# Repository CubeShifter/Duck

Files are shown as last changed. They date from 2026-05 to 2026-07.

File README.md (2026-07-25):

# Duck
An rp2040 devboard that can be coded up to play a loud noise when pressed with a keyboard switch. The original goal for the project was to make it play a loud noise of your choice when you press the switch, but i wanted to make it more customizable so now its a pcb that you can do whatever with. sadly i did privitize my lapse links cause i put some pii in them so you will just have to trust my :hs:

Screenies!

Schematic
Screenshot 2026-07-24 at 8 37 37 PM

I foget what its called(Dont mind the drc errors i forgot to rerun it)
Screenshot 2026-07-24 at 8 38 18 PM

3d Model of top:
  Screenshot 2026-07-24 at 8 39 08 PM

3d model of bottom:

Screenshot 2026-07-24 at 8 39 43 PM

# Steps for recreation:
Get the pcb fabricated, and solder on the componenets. I would highly reccomend PCBA, but you could also hand solder it. Once you build it, you can flash code on it like an rp2040 devboard. I want to see how people use the key and audio, so you should try using it somehow!

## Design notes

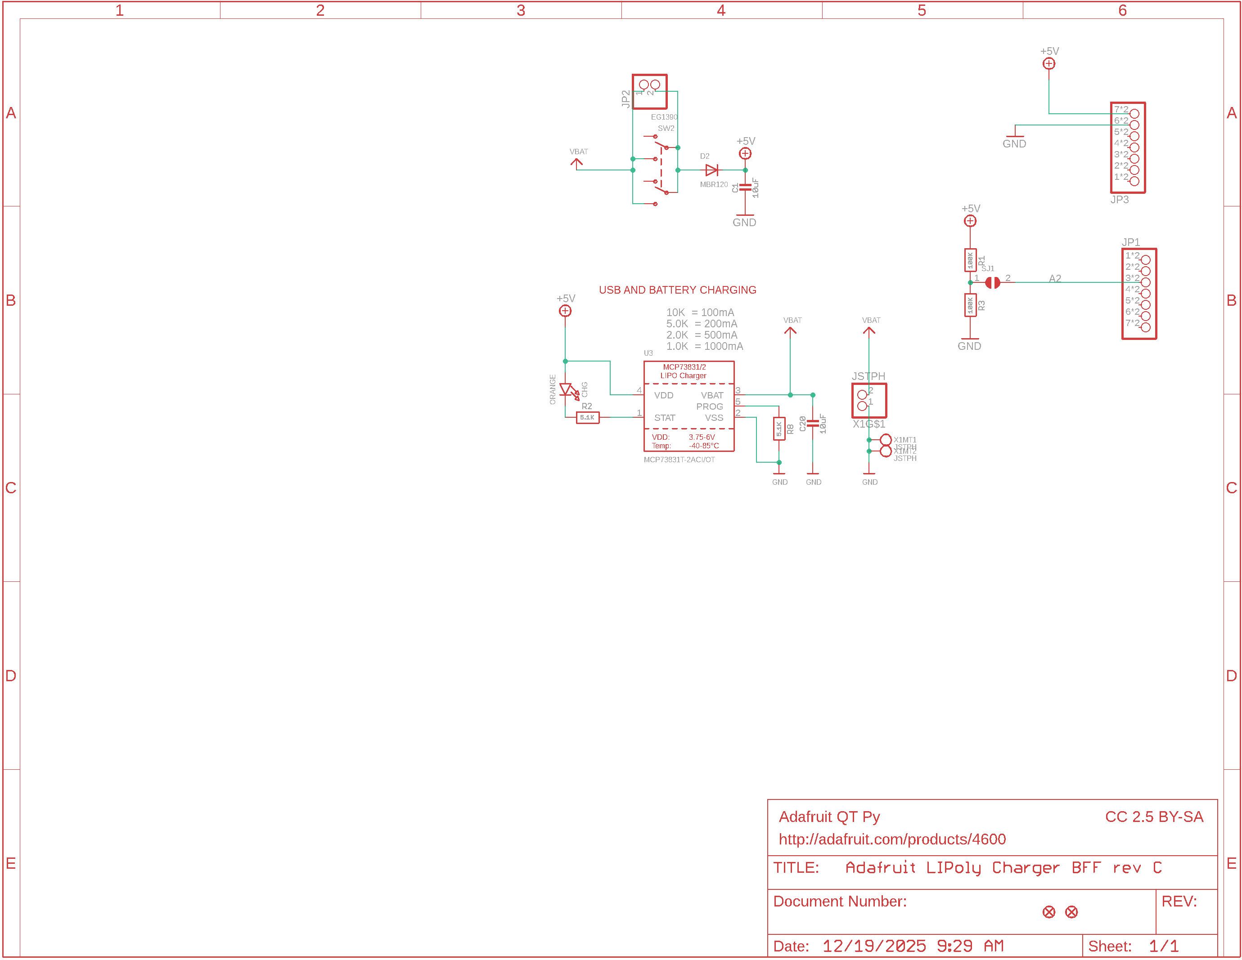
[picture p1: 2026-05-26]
Adafruit_Lipo_Bff_Sch.png

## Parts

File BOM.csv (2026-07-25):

Name | Usecase | Quantity | Unit Price(USD) | Link
RP2040 | Micrcontroller | 1 | 0.99 | https://www.lcsc.com/product-detail/C2040.html?s_z=n_q_t_rp2040
YXC Crystal Oscillators X322512MSB4SI | Oscillator | 1 | 0.48 | https://www.lcsc.com/product-detail/C9002.html?s_z=n_q_C9002&globalKeyword=C9002
Korean Hroparts Elec TYPE-C-31-M-12 | USBC thingy | 1 | 0.85 | https://www.lcsc.com/product-detail/C165948.html?s_z=n_q_C165948&globalKeyword=C165948
W25Q128JVS | Flash Chip | 1 | 2.5 | https://www.lcsc.com/product-detail/C97521.html?s_z=n_q_W25Q128JVS
XUNPU TS-1088-AR02016 | Reset Button | 1 | 0.05 | https://www.lcsc.com/product-detail/C720477.html?s_z=n_q_C720477&globalKeyword=C720477
NCP1117-3.3_SOT223 | 3.3v regulator | 1 | 0.032 | https://www.lcsc.com/product-detail/C20546.html?s_z=n_q_p_NCP1117-3.3_SOT223
MAX98357A | Audio Amp | 1 | 1.34 | https://www.lcsc.com/product-detail/C910544.html?s_z=n_q_MAX98357A
Mini Oval Speaker | Speaker! | 1 | 1.95 | https://www.adafruit.com/product/4227
3.7v battery | Battery!!!!! | 1 | 5.95 | https://www.adafruit.com/product/4237
SK6812Mini-E | Keeb Led | 1 | 0.44 | https://www.lcsc.com/product-detail/C5149201.html
HMX Bruise | Keyboard switch | 1 | 0.42 | https://milktooth.com/products/bruise
YAGEO CC0402KRX7R7BB104 | 0.1uF Ceramic Capacitor | 14 | 0.0086 | https://www.lcsc.com/product-detail/C60474.html?s_z=n_q_t_0.1uf%2520402
Samsung Electro-Mechanics CL05A105KO5NNNC | 1uf capacitor | 2 | 0.0091 | https://www.lcsc.com/product-detail/C29266.html?s_z=n_q_t_1uf%2520402
Samsung Electro-Mechanics CL10A106MA8NRNC | 10uf cap | 5 | 0.1258 | https://www.lcsc.com/product-detail/C96446.html?s_z=n_q_t_10uf%2520603
YAGEO RC0402FR-0727RL | 27 ohm resistor | 2 | 0.0048 | https://www.lcsc.com/product-detail/C138021.html?s_z=n_q_t_27ohm%2520402
YAGEO RC0402FR-071KL | 1k ohm resistor | 2 | 0.006 | https://www.lcsc.com/product-detail/C106235.html?s_z=n_q_t_1kohm%2520402
YAGEO RC0402FR-0710KL | 10k ohm resistor | 1 | 0.006 | https://www.lcsc.com/product-detail/C60490.html?s_z=n_q_t_10kohm%2520402
YAGEO RC0402FR-07100KL | 100k ohm resistor | 1 | 0.006 | https://www.lcsc.com/product-detail/C60491.html?s_z=n_q_t_100kohm%2520402
YAGEO RC0402FR-071ML | 1m ohm resistor | 1 | 0.006 | https://www.lcsc.com/product-detail/C138033.html?s_z=n_q_t_1000kohm%2520402
YAGEO RC0402FR-07330RL | 330 ohm resistor | 1 | 0.006 | https://www.lcsc.com/product-detail/C105875.html?s_z=n_q_t_330ohm%2520402
YAGEO RC0402FR-072KL | 2k ohm resistor | 2 | 0.006 | https://www.lcsc.com/product-detail/C60488.html?s_z=n_q_t_2kohm%2520402
YAGEO RC0402FR-075K1L | 5.1k ohm resistor | 2 | 0.006 | https://www.lcsc.com/product-detail/C105872.html?s_z=n_q_t_5.1kohm%2520402

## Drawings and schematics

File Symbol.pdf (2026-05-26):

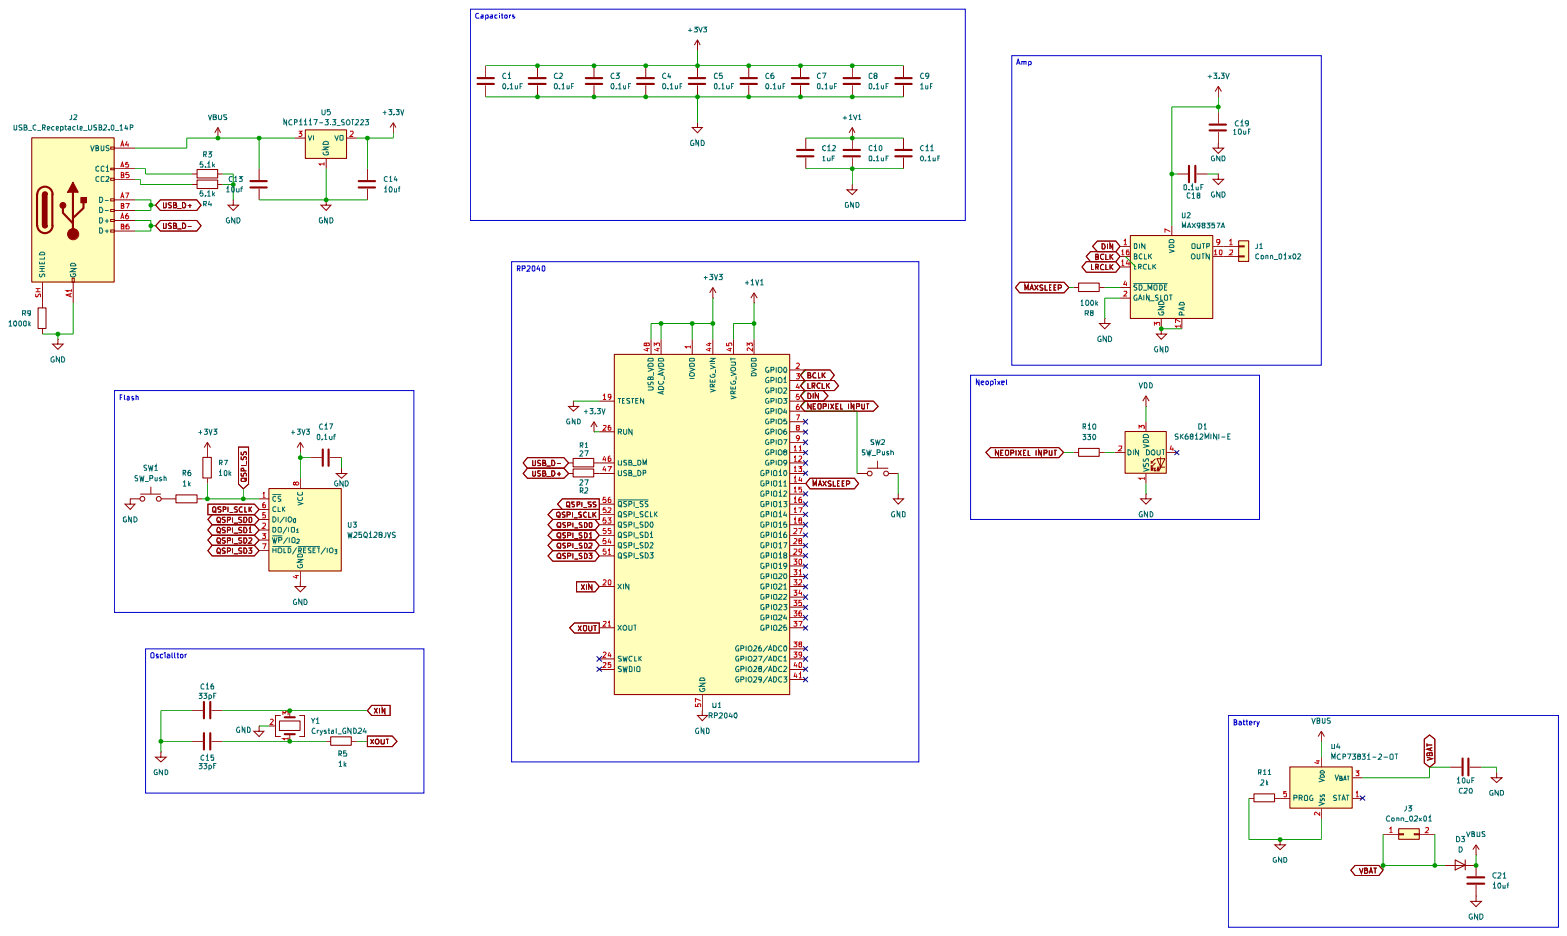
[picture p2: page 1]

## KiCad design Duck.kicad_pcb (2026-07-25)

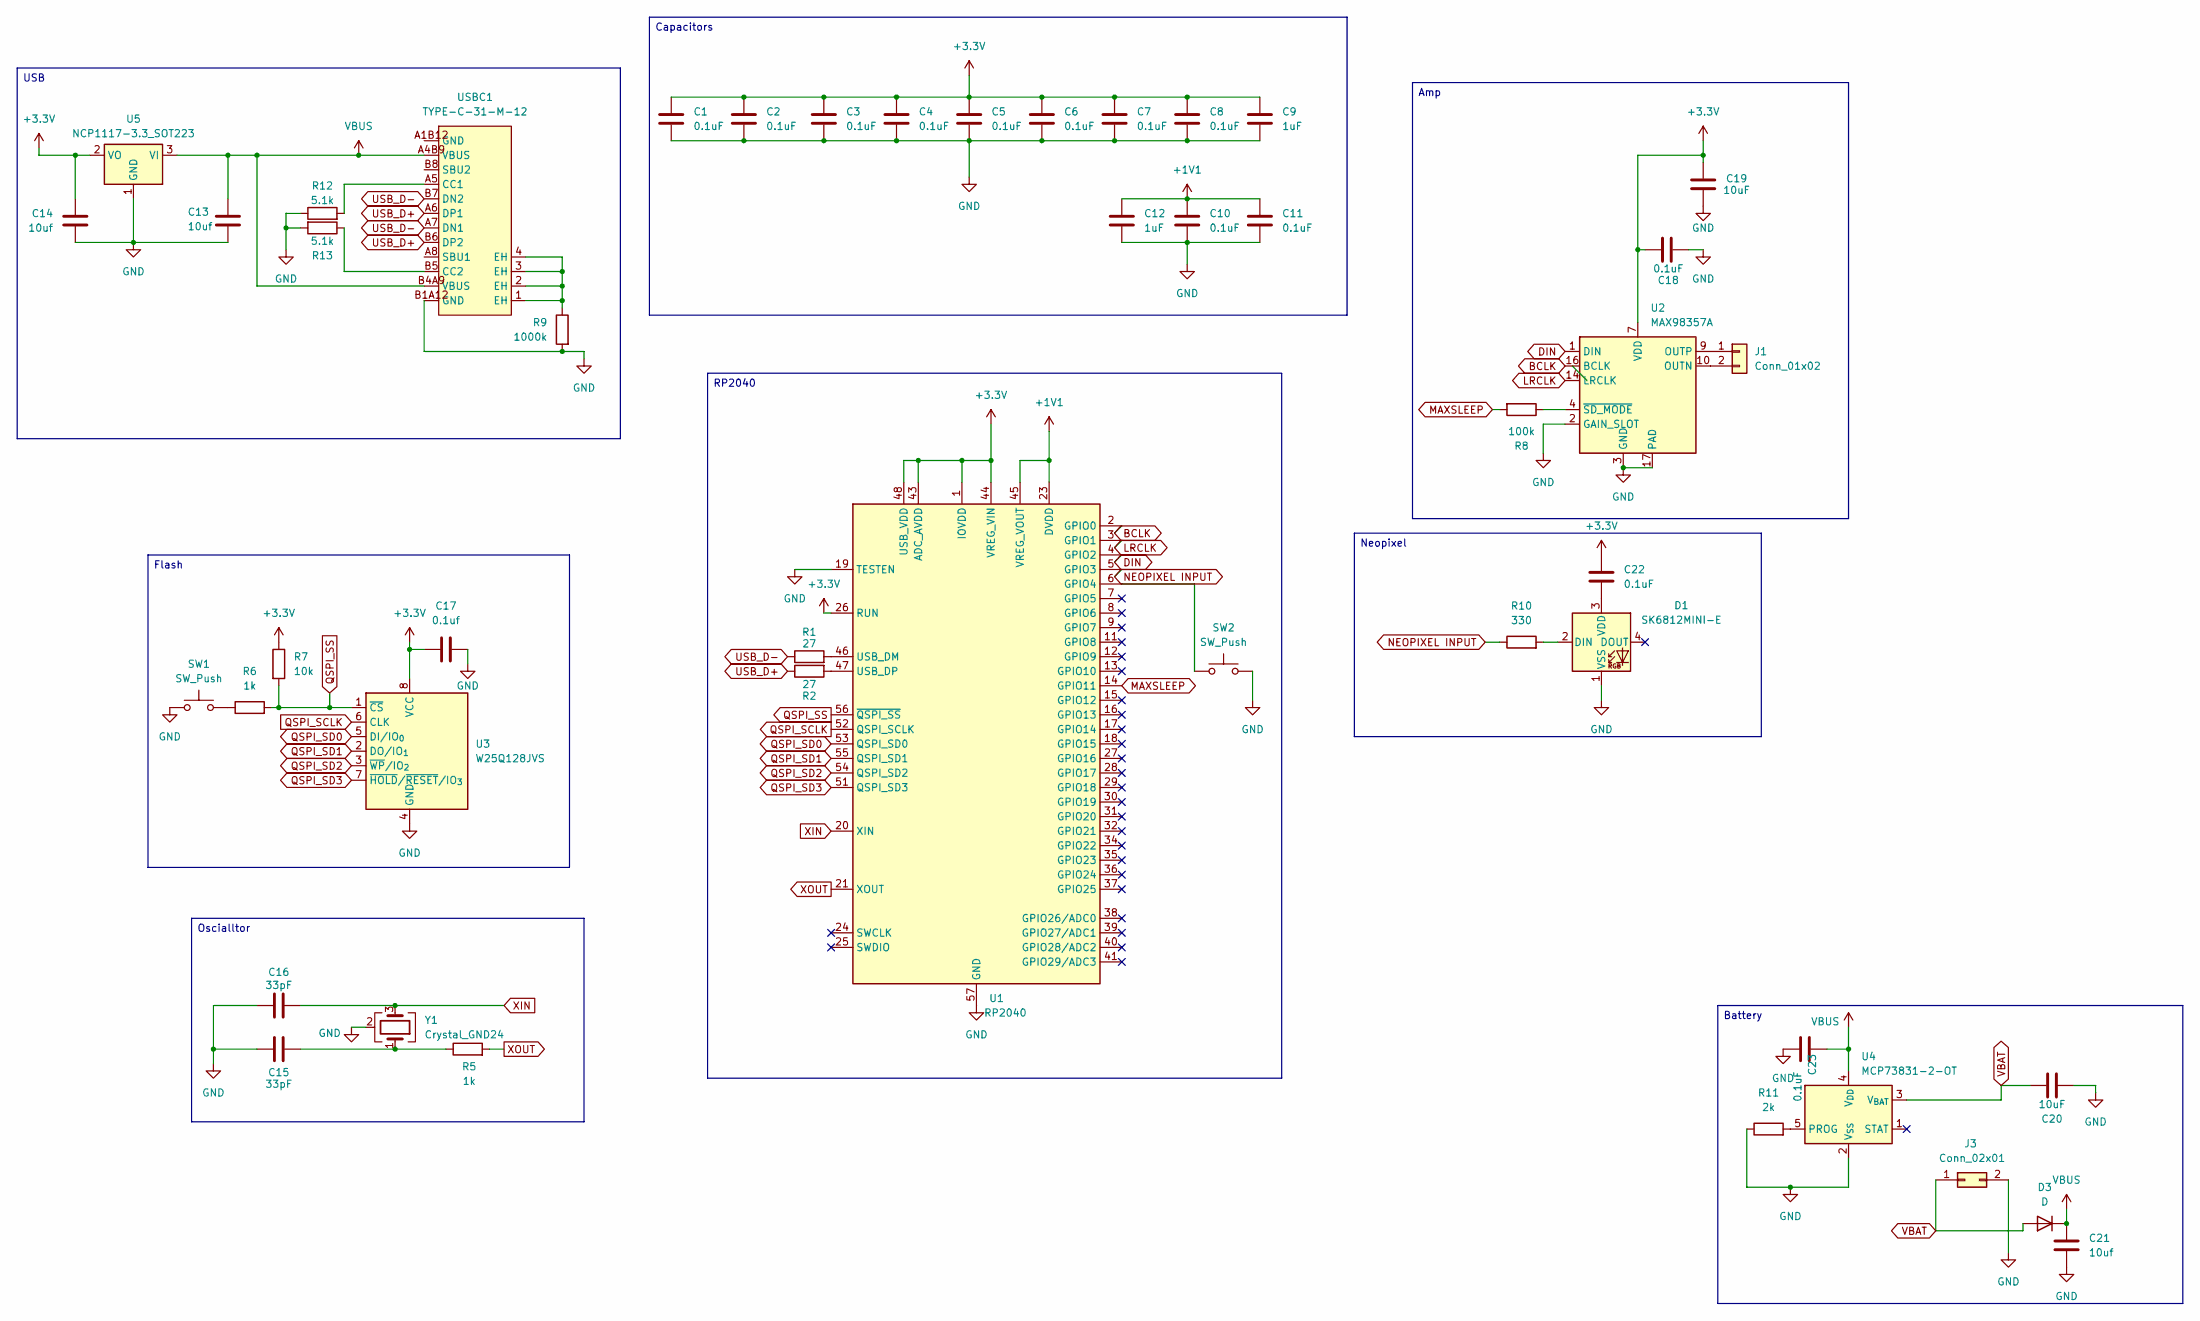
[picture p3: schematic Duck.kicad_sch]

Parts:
C1, C2, C3, C4, C5, C6, C7, C8, C10, C11, C18, C22, C23: 0.1uF; C_0402_1005Metric
C9, C12: 1uF; C_0402_1005Metric
C13, C14, C21: 10uf; C_0603_1608Metric
C15, C16: 33pF; C_0402_1005Metric
C17: 0.1uf; C_0402_1005Metric
C19, C20: 10uF; C_0603_1608Metric
D1: SK6812MINI-E; LED_SK6812MINI-E_3.2x2.8mm_P1.5mm_ReverseMount
D3: D; D_0402_1005Metric
J1: Conn_01x02; PinSocket_1x02_P2.54mm_Vertical
J3: Conn_02x01; PinSocket_1x02_P2.54mm_Vertical
R1, R2: 27; R_0402_1005Metric
R5, R6: 1k; R_0402_1005Metric
R7: 10k; R_0402_1005Metric
R8: 100k; R_0402_1005Metric
R9: 1000k; R_0402_1005Metric
R10: 330; R_0402_1005Metric
R11: 2k; R_0402_1005Metric
R12, R13: 5.1k; R_0402_1005Metric
SW1: SW_Push; SW-SMD_L3.9-W3.0-P4.45
SW2: SW_Push; SW_Cherry_MX_1.00u_PCB
U1: RP2040; QFN-56-1EP_7x7mm_P0.4mm_EP3.2x3.2mm
U2: MAX98357A; TQFN-16-1EP_3x3mm_P0.5mm_EP1.23x1.23mm
U3: W25Q128JVS; SOIC-8_5.3x5.3mm_P1.27mm
U4: MCP73831-2-OT; SOT-23-5
U5: NCP1117-3.3_SOT223; SOT-223-3_TabPin2
USBC1: TYPE-C-31-M-12; USB-C_SMD-TYPE-C-31-M-12_1; MPN TYPE-C-31-M-12; LCSC Part C165948
Y1: Crystal_GND24; CRYSTAL-SMD_4P-L3.2-W2.5-BL

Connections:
+1V1: C10.1, C11.1, C12.1, U1.23 (DVDD), U1.45 (VREG_VOUT), U1.50 (DVDD)
+3.3V: C1.1, C2.1, C3.1, C4.1, C5.1, C6.1, C7.1, C8.1, C9.1, C14.1, C17.1, C18.2, C19.2, C22.1, R7.1, U1.1 (IOVDD), U1.10 (IOVDD), U1.22 (IOVDD), U1.26 (RUN), U1.33 (IOVDD), U1.42 (IOVDD), U1.43 (ADC_AVDD), U1.44 (VREG_VIN), U1.48 (USB_VDD), U1.49 (IOVDD), U2.7 (VDD), U2.8 (VDD), U3.8 (VCC), U5.2 (VO)
A+: J1.1, U2.9 (OUTP)
A-: J1.2, U2.10 (OUTN)
BCLK: U1.2 (GPIO0), U2.16 (BCLK)
DIN: U1.4 (GPIO2), U2.1 (DIN)
GND: C1.2, C2.2, C3.2, C4.2, C5.2, C6.2, C7.2, C8.2, C9.2, C10.2, C11.2, C12.2, C13.2, C14.2, C15.1, C16.1, C17.2, C18.1, C19.1, C20.2, C21.2, C23.2, D1.1 (VSS), J3.2, R9.2, R11.1, R12.1, R13.2, SW1.1, SW2.2, U1.19 (TESTEN), U1.57 (GND), U2.2 (GAIN_SLOT), U2.3 (GND), U2.11 (GND), U2.15 (GND), U2.17 (PAD), U3.4 (GND), U4.2 (V_{SS}), U5.1 (GND), USBC1.A1B12 (GND), USBC1.B1A12 (GND), Y1.2 (G), Y1.4 (G)
LRCLK: U1.3 (GPIO1), U2.14 (LRCLK)
MAXSLEEP: R8.2, U1.14 (GPIO11)
NEOPIXEL INPUT: R10.1, U1.5 (GPIO3)
unnamed: C15.2, R5.1, Y1.1
unnamed: D1.2 (DIN), R10.2
unnamed: C22.2, D1.3 (VDD)
unnamed: R6.1, SW1.2
unnamed: R9.1, USBC1.1 (EH), USBC1.2 (EH), USBC1.3 (EH), USBC1.4 (EH)
unnamed: SW2.1, U1.6 (GPIO4)
unnamed: R1.2, U1.46 (USB_DM)
unnamed: R2.2, U1.47 (USB_DP)
unnamed: R8.1, U2.4 (~SD_MODE)
unnamed: R11.2, U4.5 (PROG)
unnamed: R12.2, USBC1.A5 (CC1)
unnamed: R13.1, USBC1.B5 (CC2)
QSPI_SCLK: U1.52 (QSPI_SCLK), U3.6 (CLK)
QSPI_SD0: U1.53 (QSPI_SD0), U3.5 (DI/IO_{0})
QSPI_SD1: U1.55 (QSPI_SD1), U3.2 (DO/IO_{1})
QSPI_SD2: U1.54 (QSPI_SD2), U3.3 (~WP/IO_{2})
QSPI_SD3: U1.51 (QSPI_SD3), U3.7 (~HOLD/~RESET/IO_{3})
QSPI_SS: R6.2, R7.2, U1.56 (~QSPI_SS), U3.1 (~CS)
USB_D+: R2.1, USBC1.A6 (DP1), USBC1.B6 (DP2)
USB_D-: R1.1, USBC1.A7 (DN1), USBC1.B7 (DN2)
VBAT: C20.1, D3.2 (A), J3.1, U4.3 (V_{BAT})
VBUS: C13.1, C21.1, C23.1, D3.1 (K), U4.4 (V_{DD}), U5.3 (VI), USBC1.A4B9 (VBUS), USBC1.B4A9 (VBUS)
XIN: C16.2, U1.20 (XIN), Y1.3
XOUT: R5.2, U1.21 (XOUT)

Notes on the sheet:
RP2040
Neopixel
Flash
USB
Amp
Capacitors
Battery
Oscialltor

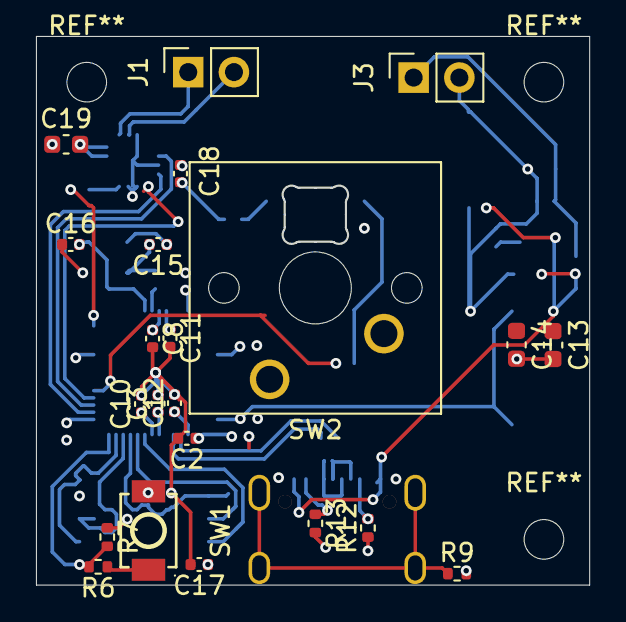
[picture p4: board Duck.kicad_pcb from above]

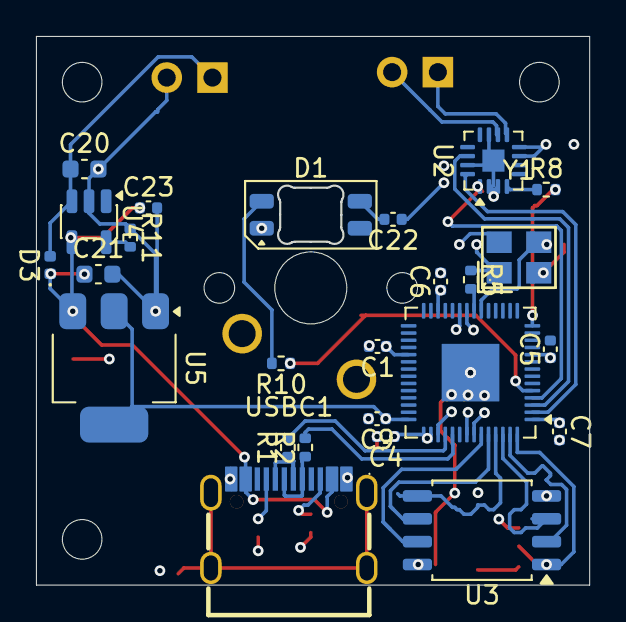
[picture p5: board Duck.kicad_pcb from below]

Board: 4 copper layers, 30.7 x 30.5 mm, 47 parts (25 on the bottom side), 34 nets.

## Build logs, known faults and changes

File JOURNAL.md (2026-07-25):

---
title: "Duck?"
author: "Kian Desh"
description: "A fidget toy that lets you press a keyboard switch and play a noise"
created_at: "2026-05-3"
---
# Bit of May 5th and 6th: Kinda figured out what parts I want.

I spent some time reasearching what parts I want, and made a few cart selections with what I want. I actually think I'm gonna make my own devboard so it's gonna be a bit harder but I got this. The sites i used were adafruit, digikey and aliexpress.
Screenshot 2026-05-06 at 7 05 44 PM

Screenshot 2026-05-06 at 7 10 39 PM

**Total time spent: 40 mins**

# May 6th: Read a bit about how to make an RP2040 board and failed to use Kicad.

I started using the hack club guides for designing an rp2040 board, a lot of it was just reading it and I placed down one thing in KiCad Screenshot 2026-05-07 at 5 26 12 PM

**Total time spent: 30 mins**

# May 7th: Started designing the pcb

I used the hackclub guides and starting getting the basics of the boards down and just getting better at learning KiCad. I also now know what capictors do. Hardware is fun :) Screenshot 2026-05-08 at 9 28 18 AM

**Total time spent: 30 mins**

# May 8th: Made the USB, Oscillator and started on the Flash

The hackclub guide is so nice, I made a lil oscillator thing which taught me what an oscialltor is also Screenshot 2026-05-08 at 9 50 22 PM. I also made a usb port thing so my circuit will have usb power, and I will implement battery charging later.![Uploading Screenshot 2026-05-08 at 9.54.40 PM.jpg…]()
Screenshot 2026-05-08 at 9 51 22 PM
Didnt really get that far on the flash, but I know how it works now.

**Total time spent: 1 hour**

# May 9th-10th: Finished Flash, Researched audio/battery charging, started on audio.

So I finished the flash, and thats all for the Hackclub guides.Screenshot 2026-05-12 at 6 30 22 PM Then I looked at how some circuts use audio and battery, gave up on battery because it confused me and focused on audio. For audio I first learnt which chip I want to use, the MAX98375A. I started looking at the datasheets that confused me, so I found a prebuilt board that makes it easier to interface with the chip and copied the schematic for it. W adafruit.Screenshot 2026-05-12 at 7 01 19 PM I did learn how i2s works

**Total time spent: 2 hours 20 mins**

# May 18th: Worked on the MAX98375A and MCP73831
For context, today is may 25th and my lapse is being weird so my recollection of what happened won't be the best. I definetly worked on audio and got the wiring pretty easy as the adafruit guide on it was pretty good, and also claude was being useful. Screenshot 2026-05-25 at 12 00 26 PM This image is my current schmatic, but at that point I didn't have the MAXSLEEP pin and some of the resistor and cap values were probably off. I also worked on the lipo circuit, which I orignally thought was going to be off before it got pressed, but that wont work as the RP2040 takes a couple second to boot up. Instead its gonna be in deepsleep mode until the keyboard switch gets pressed which I also wired up. Screenshot 2026-05-25 at 12 32 40 PM This is my lipo circuit currently, but like the amp I think I had changed some values to make it go from a 200mah to 500mah charging rate. I also copied the adafruit schematic for it along with some help from claude. I know I shouldnt be using AI but it's kinda helpful especially with me taaking an ambitious hardware project. 
**Total time spent: 2 hours**

# May 20th: Worked on the charging chip and audio chip
For context, today is may 25th and my lapse is being weird so my recollection of what happened won't be the best. I definetly worked on audio and got the wiring pretty easy as the adafruit guide on it was pretty good, and also claude was being useful. Screenshot 2026-05-25 at 12 00 26 PM This image is my current schmatic, but at that point I didn't have the MAXSLEEP pin and some of the resistor and cap values were probably off. I also worked on the lipo circuit, which I orignally thought was going to be off before it got pressed, but that wont work as the RP2040 takes a couple second to boot up. Instead its gonna be in deepsleep mode until the keyboard switch gets pressed which I also wired up. Screenshot 2026-05-25 at 12 32 40 PM This is my lipo circuit currently, but like the amp I think I had changed some values to make it go from a 200mah to 500mah charging rate. I also copied the adafruit schematic for it along with some help from claude. I know I shouldnt be using AI but it's kinda helpful especially with me taaking an ambitious hardware project. 
**Total time spent: 40 mins**

# May 22nd: Revised my schematic and it should be done.
So I posted my schematic in the hackclub slack, and some few really nice people gave me some feedback. First of all they told me to run ERC, and I had to clean up the mess I had made. So I first of all put the litlle x thingies on any pins that were unused, and then also fixed some wires that werent connected properly. I also updated the amp and charging chip, I forget what i did to the amp but i changed the charging chip to 500mAh, which would be much better. I also asked claude and questioned my life choices, and the best way to do what I want is the way I am going. This is an image of my finalized schematic. [Symbol.pdf](https://github.com/user-attachments/files/28236979/Symbol.pdf)

**Total time spent: 1 hour 30 mins**

# May 23rd: Looked for footprints and imported them and it was being annoying.
So I started to assign footprints to all my parts. I thought this would be relatively easy as probably within the first hour I was done withe everything exept a few. The remaining three, however, were not easy. The USB receptable was annoying because I had to import it from jlcpcb which did not have an easy export so I had to download a tool just to do it and had to work with terminal which was really annoying. I eventually got that, but I also had to change the crystal to make it work better, but after that it was fine. The last thing which was by far the most annoying was the keyboard switch. I had to look through a repo and couldnt find anything and then looked through another one then went insane and realised I didnt need a keyboard switch footprint with an LED as they are seperate. Overall this was a really annoying process, and I did not help that I had to blow my nose every other second cause I was really sick. .Screenshot 2026-05-25 at 4 10 49 PM

**Total time spent: 2 hours 30 mins**

# May 24th:Started and failed on the footprint.
This was really annoying. I first of all imported all the parts into the the footprint, and it worked fine. I played around with arrangement and I had enough space. I then reimported my schematic, and saw some errors with the USB. I then tried for 30 mins to fix them and managed to find a correct footprint, and fore some reason whenever I reimport a footprint my KiCad crashes. This was normally fine, but I pressed the wrong button but this journal and half of the last ones progress got erased. Screenshot 2026-05-25 at 4 11 15 PM
**Total time spent: 1 hour 15 mins **

# May 25th: I worked on this journal.
Whoa this is so meta, I worked really hard and forgot about the journal but I updated it

**Total time spent: 50 mins**

# May 26th: I worked on the schematic layout.
So I started reimporting the parts and started placing them. I had to play around with where everything goes as the keyboard switch and led were in the middle, so everything had to go around them. The keyboard switch and led were also really annoying to position, but after a bit of trial and error and looking at other pcbs i got it working. While placing the parts, I had to put into consideration what things should be next to each other. The image is a more updating schematic with better placements and positioned caps and wiring which happenend later. Screenshot 2026-05-31 at 2 14 33 PM
**Total time spent: 1 hour 30 mins**

# May 27th - 28th: I worked on the schematic layout, the sequel.
I had to redo the orientation because I was trying to put on caps which i got halfway through until I realized it would not work. I then decided to delete the entire thing and redo it, which looking back was a really dumb moove on my part. It did end up working eventually and the newer one is anyway more refined. I did take much longer because I had to change up the keyboard switch stuff to make room for the usb and I had to figure out how to position the led but it was all kinda deja vu esk. Screenshot 2026-05-31 at 2 27 42 PM Imagine this image wihtout the wires and caps.
**Total time spent: 2 hours**

# May 28th: I figured out which lipo I was gonna use.
This is really short journal, but with the help of claude i figured out how to do the lipo. I thought that I can just do around a 1.25 cube inch space, but i can do more using the pythagorem theorum. i could theoretically get around a 1.4 inch big one. I decided to get this from adafruit because reverse polarity and also I actually trust that company.
**Total time spent:15 mins**

# May 28th: I figured out which lipo I was gonna use.
This is really short journal, but with the help of claude i figured out how to do the lipo. I thought that I can just do around a 1.25 cube inch space, but i can do more using the pythagorem theorum. i could theoretically get around a 1.4 inch big one. I decided to get this from adafruit because reverse polarity and also I actually trust that company.
**Total time spent:15 mins**

# May 28th: Started putting caps in place.
So I started laying out some of the caps where they should go. I was a bit confused on where some of the caps should go, but claude was aura. I put probably half of the caps on there and got the orientation correctly. While doing this I was also planning out how my circuit will flow.Screenshot 2026-05-31 at 3 00 47 PM Imagine this but with half the caps and resistors on the side and no wires.

**Total time spent:30 mins**

# May 29th: Started putting the other caps and changed the regulator.
I had to make some updates to the regulator and change it to an ap 2112k. this was actually much better and it had a smaller form factor. I also tried to get the usb wiring but didnt figure out how to tune the track lengths. I also tried to wire some other things but then realized I didnt have caps so that was a bad idea. Either way that was really unproductive but atleast I have a better regulator that also works fine with me battery. I guess ill just show the updated schametics for my image. MraowrScreenshot 2026-05-31 at 4 05 47 PM

**Total time spent:30 mins**

# July 18th: its been a while
havent updated this in a while, and i didnt really do anything yet. I just want to say im back, and gonna wrap this up in the next 5 days. This time im gonna use a 4 layer pcb to keep my traces much cleaner, and now i know a lot of cad so i can do cool stuff. thats all i wanted to say, meow

**Total time spent:0 mins**

# July 24th: its been a while
So well two of these hours werent logged, but i kinda finished the pcb, i redid all of the wiring and made it four layer, and made the the differential pairs work better. this was actually pretty fun and yeah it was basically building a tiny devboard with a keyboard switch and speaker thingy. idk what else to say 4 layers made it sooo much easier.

Screenshot 2026-07-24 at 8 31 25 PM
Screenshot 2026-07-24 at 8 31 07 PM

**Total time spent:  4 hours **

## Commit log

2026-05-06 Add new entry 'meow,moew' to BOM.csv
    [BOM.csv]
2026-05-06 Update BOM.csv header and format
    [BOM.csv]
2026-05-06 Add ID column and update BOM.csv format
    [BOM.csv]
2026-05-06 Add Mini Oval Speaker to BOM
    [BOM.csv]
2026-05-07 Remove price and store info for Mini Oval Speaker
    Removed the price and store information for the Mini Oval Speaker.
    [BOM.csv]
2026-05-08 Add journal entry for May 7th on PCB design
    Documented progress on PCB design and learning KiCad.
2026-05-13 Update JOURNAL.md with May 9th-10th entries
    Documented progress on audio and battery research, including chip selection and schematic copying.
2026-05-25 Update JOURNAL.md with recent project progress
    Added detailed entries for May 18th to May 25th, documenting work on audio and charging circuits, schematic revisions, and footprint assignments.
2026-05-26 All of the pcb stuff
    I kinda forgot to comit lol
    [Duck.kicad_pcb, Duck.kicad_sch]
2026-05-26 Hopefully this works
    [Duck.kicad_pcb, Duck.kicad_sch]
2026-05-31 Document work on schematic layout for May 26th
    Added entry for May 26th detailing work on schematic layout and time spent.
2026-05-31 Update JOURNAL.md with recent project entries
    Added new entries for May 27th to 28th detailing schematic layout work and lipo selection.
2026-07-25 Add journal entry for July 24th on PCB work
    Documented progress on PCB development and wiring improvements.
2026-07-25 welp i forgot to commit
    bascially everything, check journal.md
    [Duck.kicad_pcb, Duck.kicad_sch]
2026-07-25 Update README with detailed project information
    Expanded project description and added images for schematic and 3D models.
2026-07-25 added gerbers
    gerbers is a funny word
2026-07-25 Revise BOM format and add new components
    Updated BOM.csv to include new columns and entries.
    [BOM.csv]
2026-07-25 Update BOM.csv with new components and price changes
    [BOM.csv]
2026-07-25 Add new components to BOM.csv
    Added new components including audio amp, speaker, and battery.
    [BOM.csv]
2026-07-25 Fix resistor value and quantity for 5.1k ohm resistor
    [BOM.csv]
